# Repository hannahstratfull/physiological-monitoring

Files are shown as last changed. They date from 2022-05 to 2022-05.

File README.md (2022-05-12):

# physiological-monitoring

The primary aim of this project is to design an innovative device for the purpose of measuring physiological stress responses in humans. This is device is a wearable vest with modular physiological sensors that will allow for novel research in listening.
CAD and code for each of our sensor modules is located in their respective folders. The sensors we have designed are: an ECG module, an EMG module, an audio module, a breathing rate sensor (dubbed FlexiForce), and an IMU module. There are also designs for a handheld controller device and a PC dongle allowing for PC connectivity, as well as generic code that will allow you to design your own module should you wish.

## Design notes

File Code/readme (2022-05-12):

Code to be uploaded to the Arduino Nano 33 iOT boards for each module. Make sure you have the correct libraries installed for each module - they will all be
available through the Arduino IDE.

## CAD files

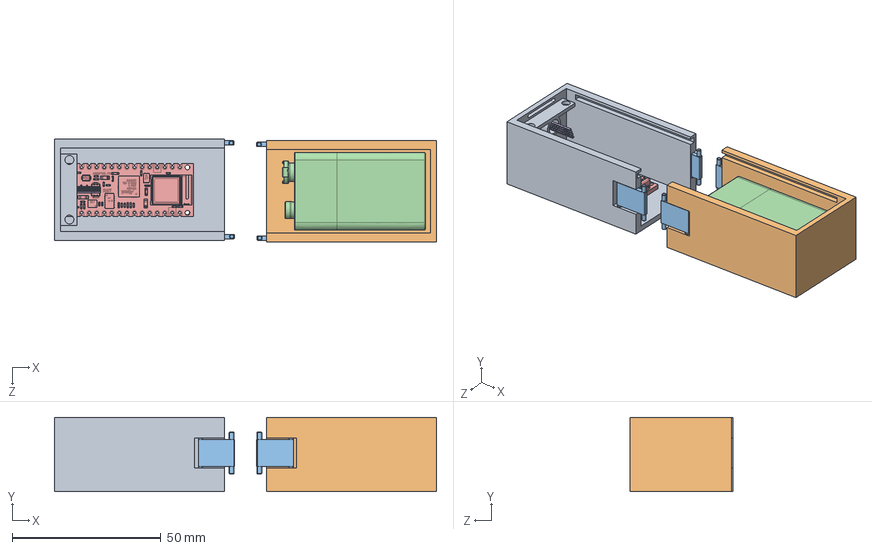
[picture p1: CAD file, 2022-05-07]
CAD/Flexiforce/hINGE fLEXI ASSEM.SLDASM
128.2 x 25.0 x 34.5 mm
Flexi bend ard box
Flexi bend bat box
Box Locking Part x 4
9V-battery
Arduino Nano 33 IoT
Terminais^Led RGB 5mm

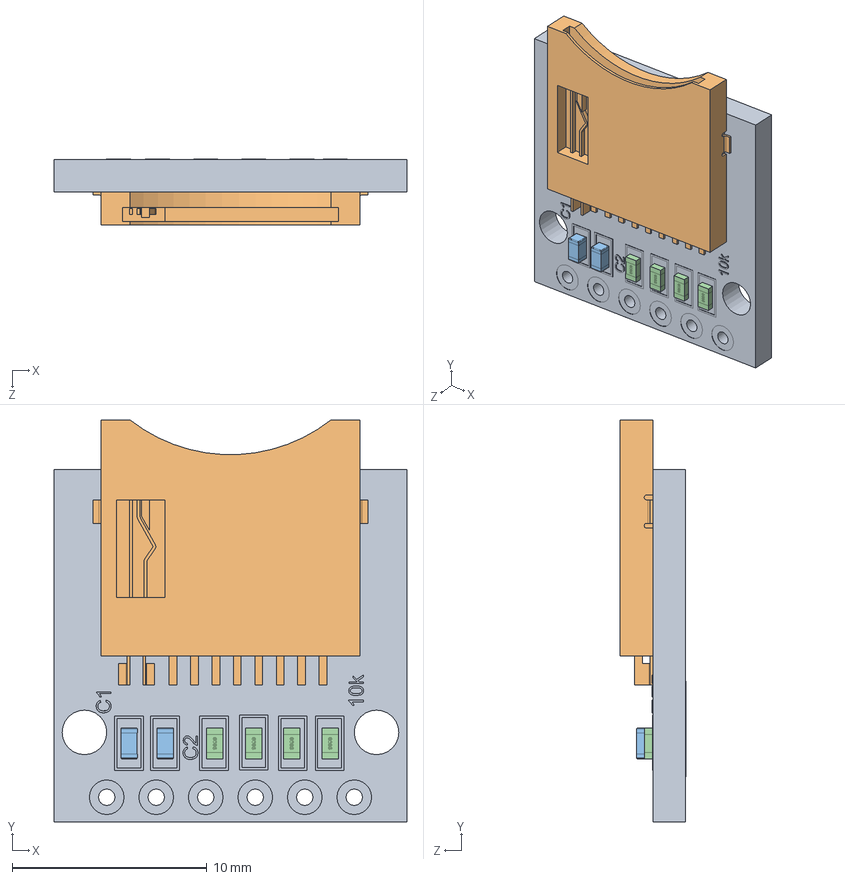
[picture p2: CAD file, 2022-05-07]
CAD/handheld device/MicroSD Card Module - 1.SLDASM
18.1 x 20.6 x 3.40 mm
Micro SD Module - 1.stp
MicroSD.stp
0603 Capacitor.stp x 2
0603 Resistor.stp x 4

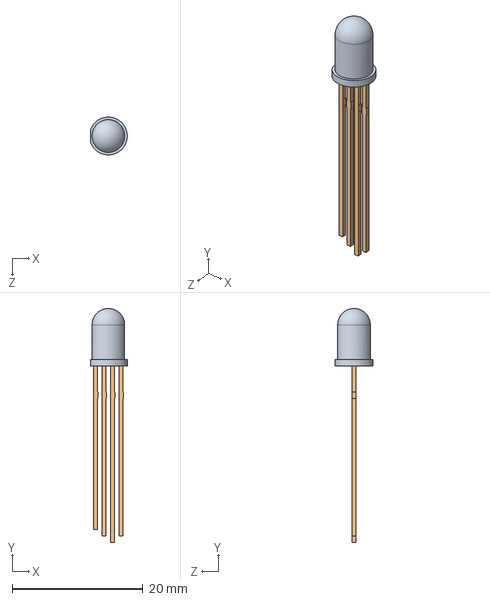
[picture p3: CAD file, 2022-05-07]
CAD/LCD/Led RGB 5mm.SLDASM
5.59 x 35.8 x 5.79 mm
Lente^Led RGB 5mm
Terminais^Led RGB 5mm

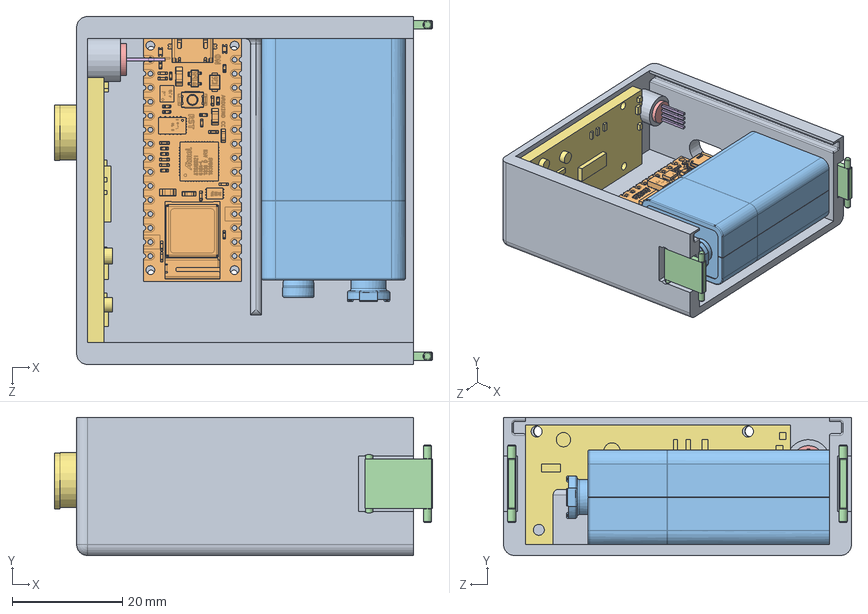
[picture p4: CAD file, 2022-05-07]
CAD/microphone/Final microphone assem.SLDASM
68.4 x 25.0 x 63.0 mm
Microphone Lid
Arduino Nano 33 IoT
9V-battery
Box Locking Part x 2
Lente^Led RGB 5mm
Terminais^Led RGB 5mm
audio module

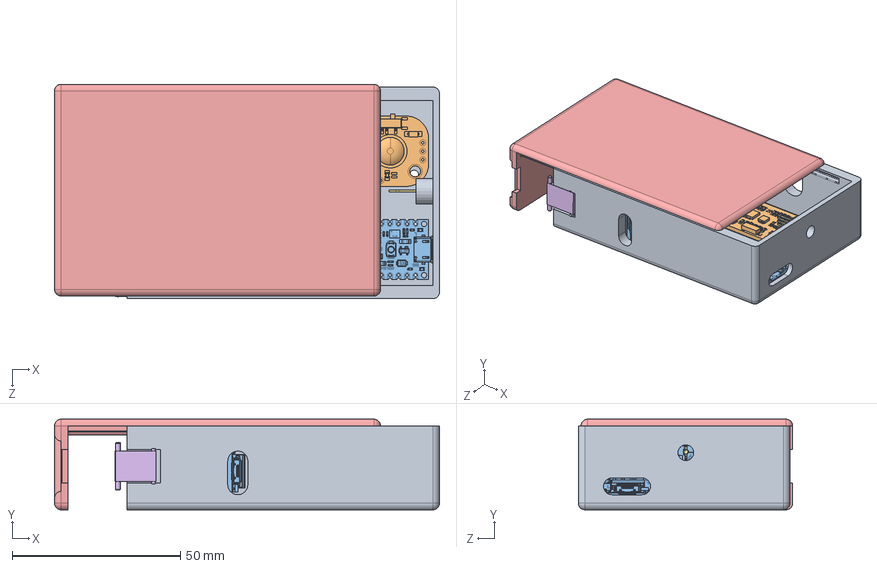
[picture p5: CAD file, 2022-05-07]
CAD/EMG/EMG Assembly.SLDASM
114.5 x 27.0 x 63.8 mm
EMG box
myoware.step
Arduino Nano 33 IoT x 2
9V-battery
EMG Box Lid
Box Locking Part x 2
Terminais^Led RGB 5mm

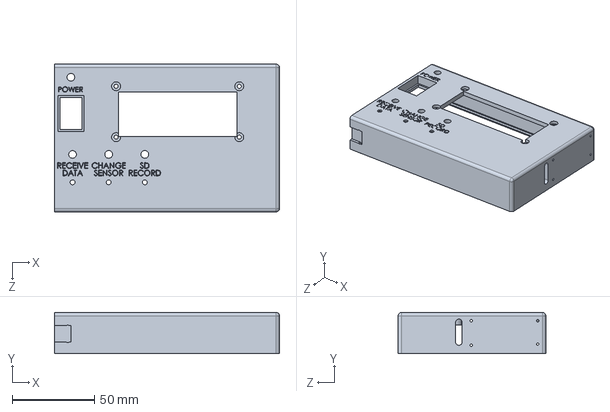
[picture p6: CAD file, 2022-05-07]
CAD/handheld device/Main casing.SLDPRT
137.0 x 25.0 x 90.0 mm

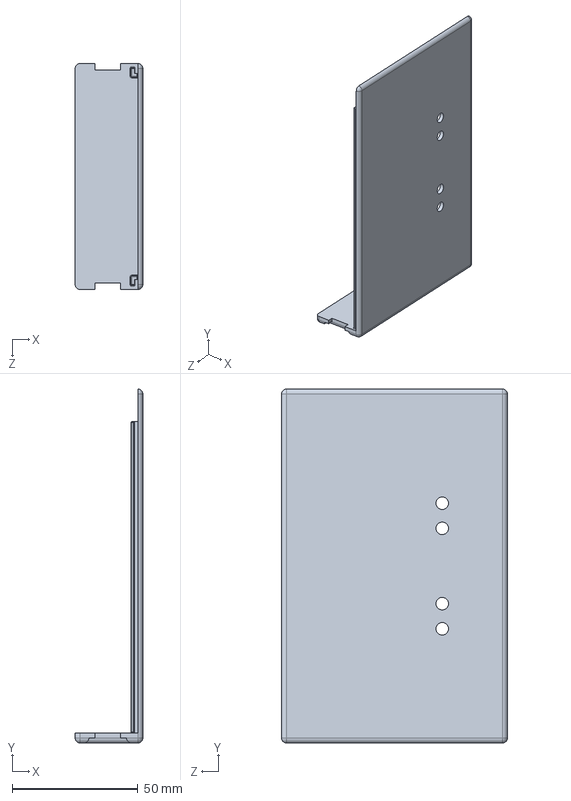
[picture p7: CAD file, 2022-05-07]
CAD/handheld device/Main Box Lid.SLDPRT
27.0 x 141.0 x 90.0 mm

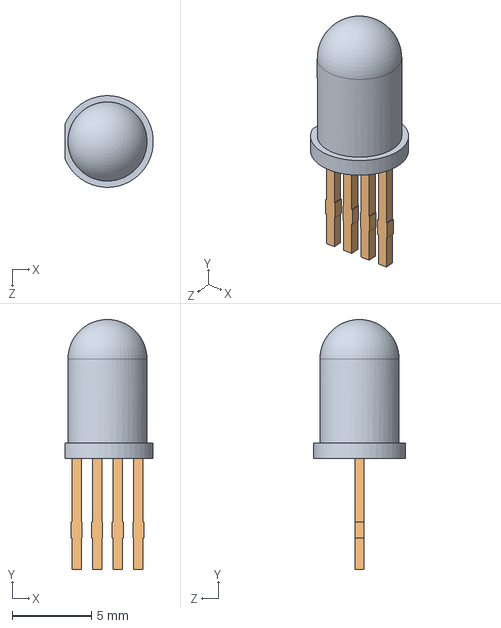
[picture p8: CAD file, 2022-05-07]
CAD/microphone/Led RGB 5mm.SLDASM
5.59 x 15.8 x 5.79 mm
Lente^Led RGB 5mm
Terminais^Led RGB 5mm

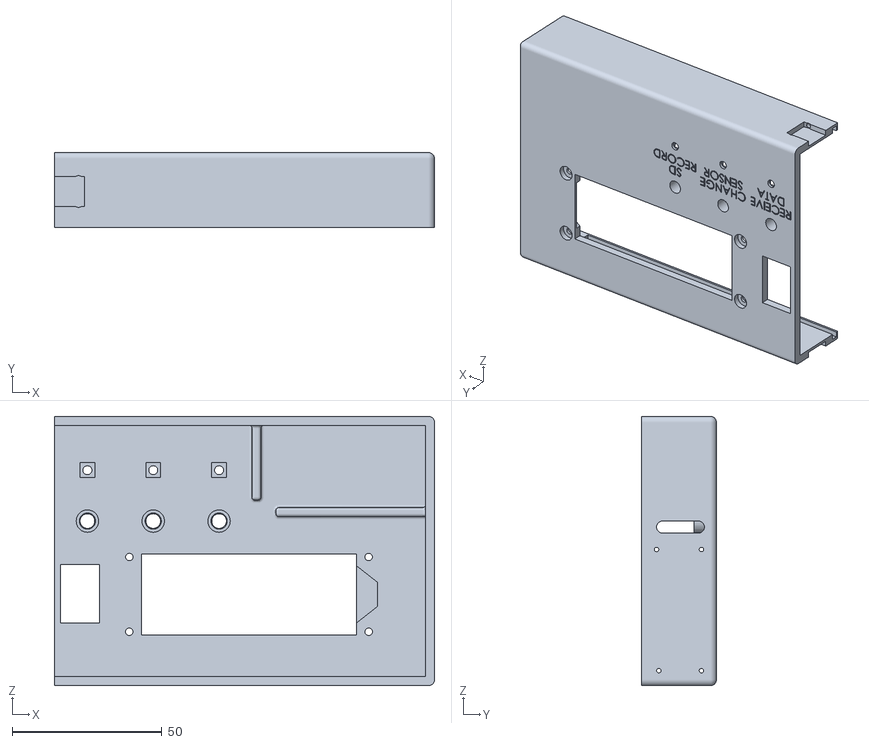
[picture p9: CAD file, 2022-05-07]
CAD/handheld device/Main casing mk2.STL
127.0 x 25.0 x 90.0

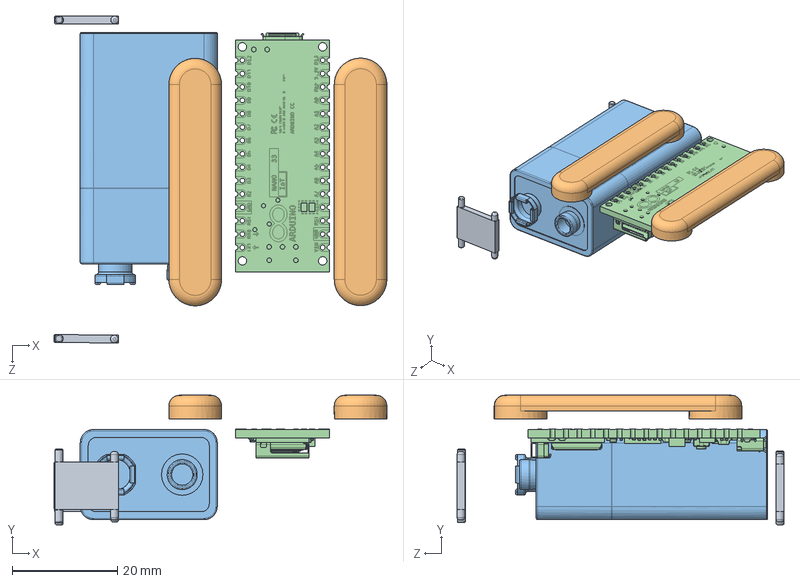
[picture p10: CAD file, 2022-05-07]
CAD/Flexiforce/Flexiforce Box.SLDASM
63.2 x 24.6 x 62.1 mm
Box Locking Part x 2
Strap holders x 2
9V-battery
Arduino Nano 33 IoT

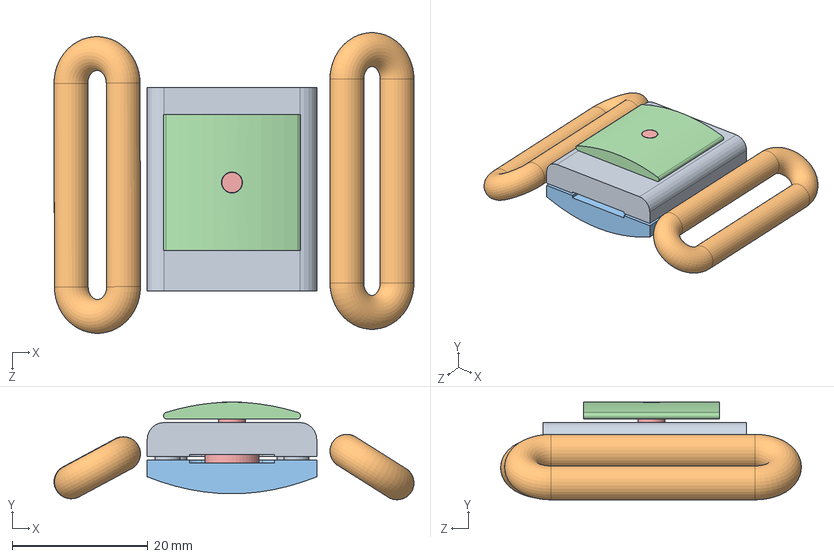
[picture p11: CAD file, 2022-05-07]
CAD/Flexiforce/Felxiforce case with hoop.SLDASM
53.1 x 14.4 x 44.3 mm
Flexiforce hoop x 2
Sensor holder part 1
button top
Button
Sensor holder upper l

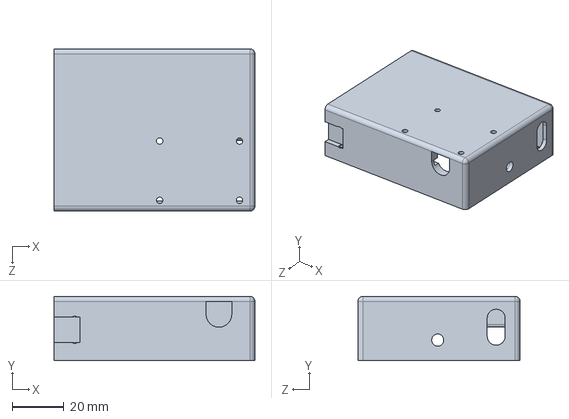
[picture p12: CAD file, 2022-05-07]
CAD/ECG/ECG box.SLDPRT
78.0 x 25.0 x 63.0 mm

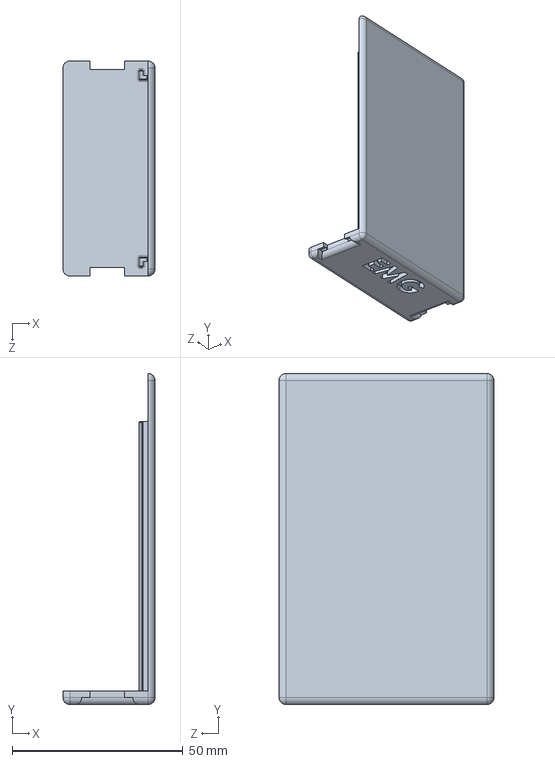
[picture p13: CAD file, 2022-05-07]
CAD/EMG/EMG Box Lid.SLDPRT
27.0 x 97.0 x 63.0 mm

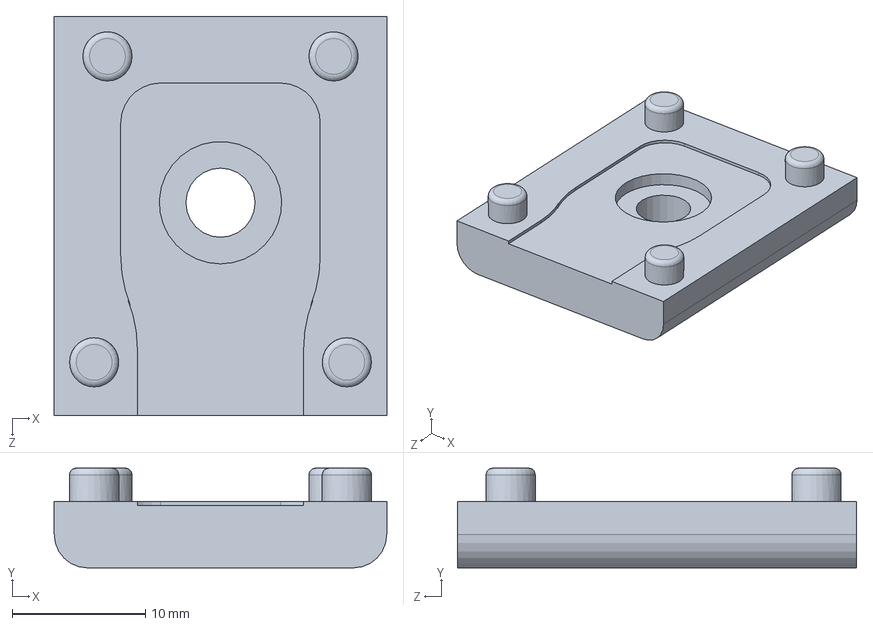
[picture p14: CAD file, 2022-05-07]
CAD/Flexiforce/Sensor holder upper l.SLDPRT
25.0 x 7.50 x 30.0 mm

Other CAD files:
CAD/handheld device/Main casing not modified final mk1.STL
CAD/handheld device/Main Box Lid Final mk1.STL
CAD/handheld device/Main Box Lid Final mk2.STL
CAD/handheld device/!!__83.SLDPRT
CAD/ECG/ECG Box Lid final mk1.STL
CAD/ECG/ECG Box Lid mk1.STL
CAD/ECG/ECG Box Lid mk2.STL
CAD/ECG/ECG Box Lid.SLDPRT
CAD/ECG/ECG box final mk1.STL
CAD/ECG/ECG box mk1.STL
CAD/ECG/ECG box mk2.STL
CAD/ECG/ECG module.SLDPRT
CAD/ECG/Name tag ECG.STL
CAD/ECG/Name tag.SLDPRT
CAD/ECG/Spacer Short final mk1.STL
CAD/ECG/Spacer Short mk2.STL
CAD/ECG/Spacer Short.SLDPRT
CAD/ECG/Spacer mk1.STL
CAD/ECG/Spacer.SLDPRT
CAD/EMG/Box Locking Part mk2.STL
CAD/EMG/Box Locking Part.STL
CAD/EMG/CE3E3_Spacer mk1.3mf
CAD/EMG/EMG Box Lid final mk1.STL
CAD/EMG/EMG Box Lid mk1.STL
CAD/EMG/EMG Box Lid mk2.STL
CAD/EMG/EMG box final mk1.STL
CAD/EMG/EMG box mk1.STL
CAD/EMG/EMG box.SLDPRT
CAD/EMG/Name tag EMG.STL
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

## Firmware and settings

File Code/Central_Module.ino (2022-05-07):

#include <ArduinoBLE.h>
#include <SPI.h>
#include <SD.h>   //SD crad library
#include "DFRobot_RGBLCD1602.h"

#define ECGIDENT 0
#define EMGIDENT 1
#define BREATHIDENT 2
#define SOUNDIDENT 3
#define IMUIDENT 4

#define BLE_UUID_DATA_SERVICE                  "180F"
#define BLE_UUID_DATA_LEVEL                    "2A19"

#define BLE_MAX_PERIPHERALS 5
#define BLE_SCAN_INTERVAL 7000
#define BLE_IDENT_INTERVAL 3000000 //in microseconds

#define SAMPLING_DELAY 40000 //in microseconds

#define BUTTON_HOLD_LIMIT 2000 //in milliseconds

#define BATTERY_PIN A0
//LED Pins
#define LEDR_SD 2
#define LEDG_SD 3
#define LEDB_SD 5
#define LEDR_POWER 6
#define LEDG_POWER A2
#define LEDB_POWER 9
#define LED_SENSOR 4
#define LED_BLE 7
//Button Pins
#define BUTTON_REF A3
#define BUTTON_BLE A1
#define BUTTON_SENSOR A6
#define BUTTON_SD A7
//LCD I2C Pins
#define SCL A5
#define SDA A4
//SD Card Pins
#define CS 10
#define MOSI 11
#define MISO 12
#define SCK 13

//LCD RGB settings
#define LCDR 255
#define LCDG 255
#define LCDB 255

BLEDevice peripherals[BLE_MAX_PERIPHERALS];
BLECharacteristic dataCharacteristics[BLE_MAX_PERIPHERALS];

DFRobot_RGBLCD1602 lcd(/*lcdCols*/16,/*lcdRows*/2);  //16 characters and 2 lines of show

int peripheralsConnected = 0;
bool bleConnected = false;
word datas[BLE_MAX_PERIPHERALS];
word data;
String sensorList[] = {"ECG","EMG","Breathing","Sound","IMU"};
String unitList[] = {"V (10bit 3.3V ADC)", "V (10bit 3.3V ADC)", "V (10bit 3.3V ADC)", "V (10bit 3.3V ADC)", "mg"};
String displayUnitList[] = {"BPM", "V", "BPM", "V", "mg"};
int thresholdList[] = {580,100, 650, 40, 1400};
String connectedSensors[BLE_MAX_PERIPHERALS];
String connectedUnits[BLE_MAX_PERIPHERALS];
String connectedDisplayUnits[BLE_MAX_PERIPHERALS];
int connectedThresholds[BLE_MAX_PERIPHERALS];
float rates[] = {0,0}; //rates are only calculated for ECG (index 0) and breathing(index 1) (in BPM)
unsigned long ratePrevTimes[] = {0,0};
int ratePrevVals[] = {0,0};
bool increasing[] = {false, false};
unsigned long rateInterval;
unsigned long startTime = 0;

bool batteryState = true;

int dataFileNum = 1;
bool countFileUpdated = false;
char fileName[] = "data";

//Button variables
bool sdState = false;
int sensorCount = 0;
bool bleState = false;
long prevSdPress = 0;
long prevSensorPress = 0;
long prevBlePress = 0;

//SD module variables
bool sdBegin = false;

void setup() {
  pinMode(LED_BLE, OUTPUT);
  Serial.begin(9600);
  // begin initialization
  if (SD.begin(CS)) {
    sdBegin = true;
  }
  lcd.init();
  lcd.setRGB(LCDR,LCDG,LCDB);
}

unsigned long loopCurrent = 0;
unsigned long loopPrev = 0;
unsigned long timeStamp = 0;
unsigned long firstTime = 0;
bool loopFunction = false;
bool newDataPrint;
bool identified = false;
bool lcdTransition = false;
unsigned long lcdPrev = millis();

float displayData = 0;

void loop() {
  File dataFile;
  detectPress();
  batteryVoltage();
  sdCheck();
  bleCheck();
  batteryLED();
  loopCurrent = micros();
  if (loopCurrent - loopPrev < SAMPLING_DELAY){    
    loopFunction= false;
  } else {
    loopFunction= true;
  }
  if (loopFunction) {
    loopPrev = loopCurrent;
    loopFunction = false;
    newDataPrint = false;
    LCDFunc();
    for(int j = 0; j < peripheralsConnected; j++) {
      Serial.println(connectedSensors[j]);
    }
    if(bleState) {
      if(sdState && sdBegin) {
        countFile();
        dataFile = SD.open(fileName, FILE_WRITE);
      }
      if(!bleConnected) {
        BLEConnect();
      }
      if(identified && micros() - startTime > BLE_IDENT_INTERVAL + BLE_SCAN_INTERVAL) {
        for ( int i = 0; i < peripheralsConnected; i++ ) {
          if (dataCharacteristics[i].valueUpdated()) {
            newDataPrint = true;
            dataCharacteristics[i].readValue( data );
            datas[i] = data;
            if (connectedSensors[i] == "ECG") {
              if(data > ratePrevVals[0] && data >= connectedThresholds[i]) {
                if (ratePrevVals[0] == 0 ) {
                  ratePrevVals[0] = data;
                } else {
                  rateInterval = micros() - ratePrevTimes[0];
                  if (!increasing[0]) {
                    //conditional to avoid detecting threshold crossing due to noise ~3 samples
                    rates[0] = 60000000/rateInterval;
                    Serial.print("interval:");
                    Serial.println(rateInterval);
                    ratePrevTimes[0] = micros();
                    increasing[0] = true;
                  }
                }
              } else if (data < connectedThresholds[i] && increasing[0]) {
                increasing[0] = false;
              }
              ratePrevVals[0] = data;
            } else if (connectedSensors[i] == "Breathing") {
              if(data > ratePrevVals[1] && data >= connectedThresholds[i]) {
                if (ratePrevVals[1] == 0 ) {
                  ratePrevVals[1] = data;
                } else {
                  rateInterval = micros() - ratePrevTimes[1];
                  if (!increasing[1]) {
                    rates[1] = 60000000/rateInterval;
                    Serial.print("interval:");
                    Serial.println(rateInterval);
                    ratePrevTimes[1] = micros();
                    increasing[1] = true;
                  }
                }
              } else if (data < connectedThresholds[i] && increasing[1]) {
                increasing[1] = false;
              }
              ratePrevVals[1] = data;
            }
          }
        }
        if (newDataPrint) {
          firstTime = firstTime > 0? micros(): firstTime;
          for ( int i = 0; i < peripheralsConnected; i++ ) {
            timeStamp = micros() - firstTime;
            Serial.print(timeStamp);
            Serial.print(",");
            Serial.print(datas[i]);
            if ( i < peripheralsConnected - 1 ) {
              Serial.print(",");
            }
            if(sdState && sdBegin) {
              dataFile.print(timeStamp);
              dataFile.print( "," );
              dataFile.print(datas[i]);
              if ( i < peripheralsConnected - 1 ) {
                dataFile.print(",");
              }
            }
          }
          Serial.print( "\n" );
          if(sdState && sdBegin) {
            dataFile.print("\n");
          }
        }
      } else {
        for ( int i = 0; i < peripheralsConnected; i++ ) {
          if (dataCharacteristics[i].valueUpdated()) {
            dataCharacteristics[i].readValue( data );
            connectedSensors[i] = sensorList[data];
            connectedUnits[i] = unitList[data];
            connectedDisplayUnits[i] = displayUnitList[data];
            connectedThresholds[i] = thresholdList[data];
            if(sdState && sdBegin) {
              dataFile.print("Time,");
              dataFile.print(sensorList[data]);
              dataFile.print("(" + unitList[data] + ")");
            }
          }
        }
        if(sdState && sdBegin) {
          dataFile.print("\n");
        }
        identified = true;
      }
      dataFile.close();
      sensorLED();
    } else if(bleConnected) {
      BLE.disconnect();
      bleConnected = false;
      for (int i = 0; i < peripheralsConnected; i++) {
        connectedSensors[i] = "";
        connectedDisplayUnits[i] = "";
        connectedUnits[i] = "";
        connectedThresholds[i] = 0;
        identified = false;
      }
    }
  }
}

void detectPress() {
  analogWrite(BUTTON_REF, 0);
  if (analogRead(BUTTON_SD) < 30) {
    if (millis() - prevSdPress >= BUTTON_HOLD_LIMIT) {
      sdState = !sdState;
      Serial.println("Pressed SD");
      prevSdPress = millis();
    }
  }
  if (analogRead(BUTTON_BLE) < 30) {
    if (millis() - prevBlePress >= BUTTON_HOLD_LIMIT) {
      bleState = !bleState;
      Serial.println("Pressed ble");
      prevBlePress = millis();
    }
  }
  if (analogRead(BUTTON_SENSOR) < 30) {
    if (millis() - prevSensorPress >= BUTTON_HOLD_LIMIT) {
      sensorCount++;
      if(sensorCount >= peripheralsConnected) {
        sensorCount -= peripheralsConnected;
      }
      Serial.println("Pressed sensor");
      prevSensorPress = millis();
      lcd.clear();
    }
  }
}

void batteryVoltage() {
  if(analogRead(BATTERY_PIN) < 600) {
    batteryState = false;
  }
}

void batteryLED() {
  if(batteryState) {
    powerLED(0,255,0);
  } else {
    powerLED(255,0,0);
  }
}

void sdCheck() {
  if(sdState){
    sdLED(0,255,0);
  } else {
    sdLED(0,0,0);
  }
}

void bleCheck(){
  if(bleState) {
    digitalWrite(LED_BLE, HIGH);
  } else {
    digitalWrite(LED_BLE, LOW);
    countFileUpdated = false;
  }
}

void LCDFunc() {
  if(bleState && identified && peripheralsConnected > 0) {
    if(lcdTransition) {
      lcd.clear();
      lcdTransition = false;
    }
    lcd.setCursor(0,0);
    lcd.print(connectedSensors[sensorCount]);
    lcd.setCursor(0,1);
    if (millis() - lcdPrev > 500) {
      lcd.setCursor(0,1);
      lcd.print("                ");
      lcd.setCursor(0,1);
      if (connectedSensors[sensorCount] == "ECG") {
        displayData = rates[0];
      } else if (connectedSensors[sensorCount] == "EMG") {
        displayData = datas[sensorCount]*3.3/1023.0;
      } else if (connectedSensors[sensorCount] == "Breathing") {
        displayData = rates[1];
      } else if (connectedSensors[sensorCount] == "Sound") {
        displayData = datas[sensorCount]*3.3/1023.0;
      } else if (connectedSensors[sensorCount] == "IMU") {
        displayData = datas[sensorCount];
      }
      lcdPrev = millis();
    }
    lcd.print(displayData, 1);
    lcd.print(connectedDisplayUnits[sensorCount]);
  } else {
    lcd.clear();
  }
}

void sensorLED() {
  int threshold  = connectedThresholds[sensorCount];
  if(datas[sensorCount] > threshold) {
    digitalWrite(LED_SENSOR, HIGH);
  } else {
    digitalWrite(LED_SENSOR, LOW);
  }
}

void powerLED(int R, int G, int B) {
  analogWrite(LEDR_POWER, R);
  analogWrite(LEDG_POWER, G);
  analogWrite(LEDB_POWER, B);
}

void sdLED(int R, int G, int B) {
  analogWrite(LEDR_SD, R);
  analogWrite(LEDG_SD, G);
  analogWrite(LEDB_SD, B);
}

void BLEConnect() {
  //Serial.println("BLE Central - Receiver");
  //Serial.println("Make sure to turn on the device.");
  // start scanning for peripheral
  BLE.begin();
  BLE.scan();
  BLE.scanForUuid( BLE_UUID_DATA_SERVICE );
  int peripheralCounter = 0;
  unsigned long startMillis = millis();
  lcd.print("Scanning...");
  while ( millis() - startMillis < BLE_SCAN_INTERVAL && peripheralCounter != BLE_MAX_PERIPHERALS ) {
    BLEDevice peripheral = BLE.available();
    if ( peripheral && peripheral.localName() == "GDPsensor" ) {
      boolean peripheralAlreadyFound = false;
      for ( int i = 0; i < peripheralCounter; i++ ) {
        if ( peripheral.address() == peripherals[i].address() ) {
            peripheralAlreadyFound = true;
          }
      }
      if ( !peripheralAlreadyFound ) {
          peripherals[peripheralCounter] = peripheral;
          peripheralCounter++;
      }
      //Serial.print("One connected!");
    }
  }
  //Serial.print("All connected!");
  BLE.stopScan();
  lcd.clear();
  lcd.print("SensorsConnected");
  startTime = micros();
  for ( int i = 0; i < peripheralCounter; i++ ) {
    peripherals[i].connect();
    peripherals[i].discoverAttributes();
    BLECharacteristic dataCharacteristic = peripherals[i].characteristic( BLE_UUID_DATA_LEVEL );
    if ( dataCharacteristic ) {
      dataCharacteristics[i] = dataCharacteristic;
      dataCharacteristics[i].subscribe();
    }
  }
  peripheralsConnected = peripheralCounter;
  bleConnected = true;
  lcdTransition = true;
}

void countFile() {
  if(!countFileUpdated) {
    if(SD.exists("filenumcounter.txt")) {
      File counterFile = SD.open("filenumcounter.txt", FILE_READ);
      dataFileNum = counterFile.parseInt() + 1;
      counterFile.close();
      SD.remove("filenumcounter.txt");
    }
    File counterFile = SD.open("filenumcounter.txt", FILE_WRITE);
    counterFile.print(dataFileNum);
    counterFile.close();
    countFileUpdated = true;
    char dataFileNumStr[2];
    itoa(dataFileNum, dataFileNumStr, 10);
    strcpy(fileName, "data");
    strcat(fileName, dataFileNumStr);
    strcat(fileName, ".txt");
  }
}

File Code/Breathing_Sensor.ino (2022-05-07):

/* prevoid - add any presetup needed for your sensor and include 
 *  the library needed!
*/

#include <ArduinoBLE.h>                         //bluetooth library
#include <Filters.h>
#include <Filters/Butterworth.hpp>

#define sensorPin A0
#define batteryPin A1
#define RPin 2
#define GPin 3
#define BPin 5
#define ECGIDENT 0
#define EMGIDENT 1
#define BREATHIDENT 2
#define SOUNDIDENT 3
#define IMUIDENT 4

#define SAMPLING_DELAY 1000 //in microseconds
#define IDENT_INTERVAL 4000 //in microseconds

boolean didMyOneTimeAction = false;             //identifier check

 // BLE IMU Service - make sure the tags match files
BLEService GDPsensor("180F");

// BLE Orientation Characteristic

BLECharacteristic sensordata("2A19", BLERead | BLENotify, 512);
int connect_millis;

void setup() {
  Serial.begin(9600);

  // begin BLE initialization
  if (!BLE.begin()) {
    Serial.println("starting BLE failed!");

    while (1);
  }
  
  /* Set a local name for the BLE device
     This name will appear in advertising packets
     and can be used by remote devices to identify this BLE device
     The name can be changed but maybe be truncated based on space left in advertisement packet
  */
  BLE.setLocalName("GDPsensor");
  BLE.setAdvertisedService(GDPsensor);     // add the service UUID
  GDPsensor.addCharacteristic(sensordata); // add the IMU characteristic
  BLE.addService(GDPsensor);               // Add the IMU service
  sensordata.writeValue("HELLO");          // set initial value for this characteristic
  
  /* Start advertising BLE.  It will start continuously transmitting BLE
     advertising packets and will be visible to remote BLE central devices
     until it receives a new connection */

  // start advertising
  BLE.advertise();

  Serial.println("Bluetooth device active, waiting for connections...");  
  String address = BLE.address();
  Serial.print("Local address is: ");
  Serial.println(address);

}

unsigned long loopCurrent = 0;
unsigned long loopPrev = 0;
bool loopFunction = false;

// Sampling frequency
const double f_s = 100; // Hz
// Cut-off frequency (-3 dB)
const double f_c = 2; // Hz
// Normalized cut-off frequency
const double f_n = 2 * f_c / f_s;

float cf = 19.5;
 
// Sixth-order Butterworth filter
auto filter = butter<6>(f_n);

void loop() {
  BatteryLED();
  // wait for a BLE central
  BLEDevice central = BLE.central();
  connect_millis = millis();

  // if a central is connected to the peripheral:
  if (central) {
    Serial.print("Connected to central: ");
    // print the central's BT address:
    Serial.println(central.address());

    // check the sensor every period
    // while the central is connected:
    while (central.connected()) {
      loopCurrent = micros();
      if (loopCurrent - loopPrev < SAMPLING_DELAY){    
        loopFunction= false;
      } else {
        loopFunction= true;
      }
      word data = 0;
      if (loopFunction == true) {
        loopPrev = loopCurrent;
        loopFunction = false;
        if (millis() - connect_millis < IDENT_INTERVAL) {
          word ident  = BREATHIDENT;
          sensordata.writeValue(ident);
          Serial.println(ident);
        }
        //fill in your sensor code here! whatever you need to get the data output
        //put the answer into the data word
        else {
          //writes the imu word value into the characteristic
          int cur_sample = 0;
          data = filter(analogRead(A0));
          float vout = (cur_sample * 5.0) / 1023.0;
          //data = vout * cf ;
          sensordata.writeValue(data);
          Serial.println(data);
        }
      }      
    }
        
    // when the central disconnects,
    Serial.print("Disconnected from central: ");
    Serial.println(central.address());

}
}

void BatteryLED() {
  if(analogRead(batteryPin) > 600) {
    BatteryLED(0,255,0);
  } else {
    BatteryLED(255,0,0);
  }
}

void BatteryLED(int R, int G, int B) {
  analogWrite(RPin, R);
  analogWrite(GPin, G);
  analogWrite(BPin, B);
}
